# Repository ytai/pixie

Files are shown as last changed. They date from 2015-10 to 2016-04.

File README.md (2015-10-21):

# Pixie
Design files for the Pixie 3W RGB LED product.

The Pixie is a 3W RGB smart LED module, designed by Ytai Ben-Tsvi and sold by Adafruit:
https://www.adafruit.com/products/2741

Image of Pixie

This is the home of its hardware design files and the firmware code.
While most users never need to worry about it, the Pixie features a PIC12F MCU, which can be reprogrammed for changing its behavior.

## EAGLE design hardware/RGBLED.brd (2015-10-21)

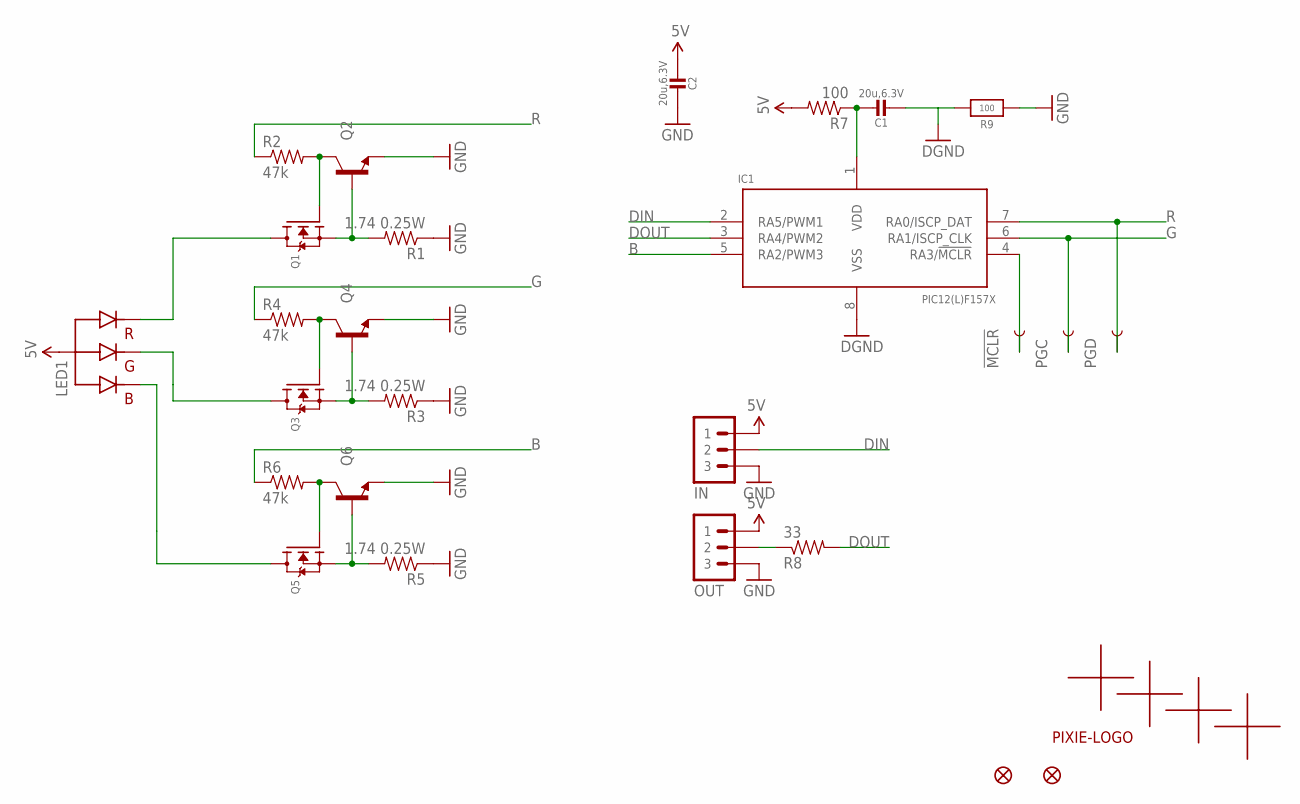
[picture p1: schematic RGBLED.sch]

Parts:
!MCLR: TEST-POINT3X4; PAD.03X.04
C1, C2: 20u,6.3V; _0805MP
IC1: PIC12(L)F157X; MSOP-8
IN: M030.1PWR+SIG; 1X03-0.1PWR+SIG
LED1: RGBLED_CA; RGBLED3W4PIN
OUT: M030.1PWR+SIG; 1X03-0.1PWR+SIG
PGC: TEST-POINT3X4; PAD.03X.04
PGD: TEST-POINT3X4; PAD.03X.04
Q1, Q3, Q5: IRLML2060TRPBF; SOT23-3
Q2, Q4, Q6: MMBT2222A; SOT23-3
R1, R3, R5: 1.74 0.25W; 1206
R2, R4, R6: 47k; 0603-RES
R7: 100; 0603-RES
R8: 33; 0603-RES
R9: 100; _0603MP
U$1, U$2, U$3, U$4: ALIGN_CROSS
U$5: PIXIE-LOGO
U$6, U$7: FIDUCIAL""; FIDUCIAL_1MM

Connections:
5V: C2.2, IN.P$1 (1), LED1.ANODE (VCC), OUT.P$1 (1), R7.2
B: IC1.5 (RA2/PWM3), R6.1
DGND: C1.2, IC1.8 (VSS), R9.2
DIN: IC1.2 (RA5/PWM1), IN.P$2 (2)
DOUT: IC1.3 (RA4/PWM2), R8.2
G: IC1.6 (RA1/ISCP_CLK), PGC.P$1, R4.1
GND: C2.1, IN.P$3 (3), OUT.P$3 (3), Q2.2 (E), Q4.2 (E), Q6.2 (E), R1.1, R3.1, R5.1, R9.1
unnamed: LED1.R (RED), Q1.3 (D)
unnamed: LED1.G (GREEN), Q3.3 (D)
unnamed: LED1.B (BLUE), Q5.3 (D)
unnamed: Q1.2 (S), Q2.1 (B), R1.2
unnamed: Q3.2 (S), Q4.1 (B), R3.2
unnamed: OUT.P$2 (2), R8.1
unnamed: !MCLR.P$1, IC1.4 (RA3/!MCLR)
unnamed: Q5.1 (G), Q6.3 (C), R6.2
unnamed: Q3.1 (G), Q4.3 (C), R4.2
unnamed: C1.1, IC1.1 (VDD), R7.1
unnamed: Q5.2 (S), Q6.1 (B), R5.2
unnamed: Q1.1 (G), Q2.3 (C), R2.2
R: IC1.7 (RA0/ISCP_DAT), PGD.P$1, R2.1

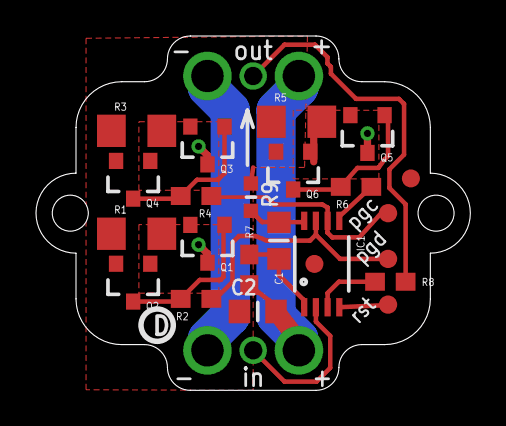
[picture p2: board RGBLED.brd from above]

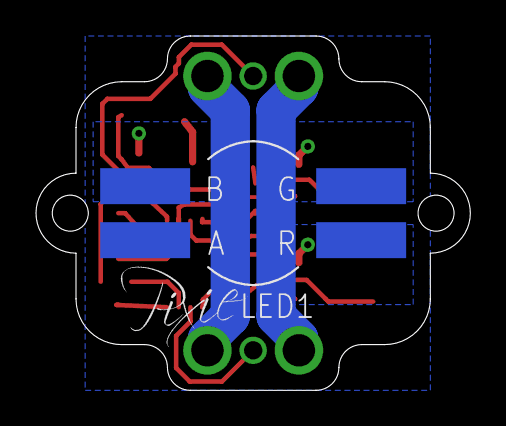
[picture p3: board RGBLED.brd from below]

Board: 2 copper layers, 24.1 x 19.7 mm, 32 parts (2 on the bottom side), 20 nets.

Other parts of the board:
U$8: PCBFEAT-REV-040

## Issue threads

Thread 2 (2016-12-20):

Low power mode?

jgilbert20, 2016-12-20:
Love the pixie but see that its drawing 3mA even when not lit. Would be great to have a low power mode that would support battery operation with long periods of inactivity.

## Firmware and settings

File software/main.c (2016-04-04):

#include <stdbool.h>
#include <stdint.h>

#include <xc.h>

#pragma config FOSC = INTOSC, WDTE = ON, CP = OFF, PLLEN = ON, BOREN = OFF, MCLRE = ON, CLKOUTEN = OFF, PWRTE = OFF, LPBOREN = ON,

#define DIN_PIN_MASK (1 << 5)
#define DOUT_PIN_MASK (1 << 4)
#define RED_PIN_MASK   (1 << 0)
#define GREEN_PIN_MASK (1 << 1)
#define BLUE_PIN_MASK  (1 << 2)
#define RGB_PIN_MASK (RED_PIN_MASK | GREEN_PIN_MASK | BLUE_PIN_MASK)

// How long of a silence on the line is considered a latch event.
// Units are 32[us] per count.
#define LATCH_TIME 30

// To convert this value to real temperature (in Celcius):
// T = K -temperature * 1.5151515, where K is some calibration constant,
// typically around 320.
static uint8_t temperature;
static uint8_t max_temp;

static uint8_t r, g, b;
uint8_t color_array[24];
volatile uint8_t bit_count;

static void InitializePwm() {
  // Fosc, no prescaler = 32MHz. Full cycle will be: 32MHz / 2^16 = 488Hz
  PWM1CLKCON = 0;
  PWM2CLKCON = 0;
  PWM3CLKCON = 0;

  // Set the period to 2^16
  PWM1PRH = PWM1PRL = 0xFF;
  PWM2PRH = PWM2PRL = 0xFF;
  PWM3PRH = PWM3PRL = 0xFF;

  // Set the phase to 0.
  PWM1PHH = PWM1PHL = 0;
  PWM2PHH = PWM2PHL = 0;
  PWM3PHH = PWM3PHL = 0;

  // Set the offset to 0.
  PWM1OFH = PWM1OFL = 0;
  PWM2OFH = PWM2OFL = 0;
  PWM3OFH = PWM3OFL = 0;

  // Set the duty cycle to 0.
  PWM1DC = 0;
  PWM2DC = 0;
  PWM3DC = 0;

  // Latch the values on next trigger.
  PWMLD = 0x07;

  // Enable the output pins.
  PWM1CON = 0x40;
  PWM2CON = 0x40;
  PWM3CON = 0x40;

  // Enable all PWM modules.
  PWMEN = 0x07;
}

static void InitializePins() {
  // Disable analog inputs.
  ANSELA = 0;
  // All outputs but Dout are low.
  LATA = DOUT_PIN_MASK;
  // Weak pull-up on Din.
  WPUA = DIN_PIN_MASK;
  // Schmidt-trigger input on Din.
  INLVLA = DIN_PIN_MASK;
  // Set the output pins as output.
  TRISA = ~(RGB_PIN_MASK | DOUT_PIN_MASK);
}

static void InitializeTimers() {
  // Timer 0 : Instruction clock / 256 = 31.25kHz (32us).
  OPTION_REG = 0x07;

  // Timer 1: Instruction clock / 8 = 1MHz (1us).
  T1CON = 0x31;

  // Timer 2: Instruction clock / 16 = 500kHz (2us).
  T2CON = 0x06;
}

static void InitializeTemperature() {
  // Enable temperature indicator at high range and FVR.
  FVRCON = 0xB0;

  // Configure ADC.
  ADCON2 = 0x00;
  // Left-aligned, Tad = 1us.
  ADCON1 = 0x20;

  // Wait for FVR to settle.
  while (!FVRRDY);
}

static inline void Timer1Delay(uint16_t count) {
  TMR1 = 0;
  while (TMR1 < count);
}

static inline uint16_t AcquireTemperature() {
  // Configure the ADC to acquire the temperature indicator.
  ADCON0 = 0x75;

  // Wait for acquisition (200us).
  Timer1Delay(200);

  // Sample.
  GO = 1;       // Start.
  while (GO);   // Wait completion.

  return ADRES;
}

static inline uint16_t AcquireVref() {
    // Enable the FVR amplifier (2x)
  FVRCON = 0xB2;

  // Configure the ADC to acquire the FVR.
  ADCON0 = 0x7D;

  // Wait for acquisition (50us).
  Timer1Delay(50);

  // Sample.
  GO = 1;       // Start.
  while (GO);   // Wait completion.

  // Disable the FVR amplifier.
  FVRCON = 0xB0;

  return ADRES;
}

static void ReadTemperature() {
  uint16_t v1 = AcquireVref();
  uint16_t t = AcquireTemperature();
  uint16_t v2 = AcquireVref();

  // Turn ADC off.
  ADCON0 = 0;

  uint8_t vavg = ((v1 >> 1) + (v2 >> 1) + 128) >> 8;
  temperature = (0xFFC0 - t) / vavg - 200;
}

static void ConvertColor() {
  r = g = b = 0;

  // Note the the temperature units used are reversed: bigger number == lower
  // temperature. So the condition below actually means temp <= max_temp.
  if (temperature >= max_temp && bit_count == 1) {
    uint8_t i;
    uint8_t const * p = color_array;

    // Read Red bits.
    for (i = 0; i < 8; ++i) {
      r |= ((*p++ >> 5) & 1) << i;
    }

    // Read Green bits.
    for (i = 0; i < 8; ++i) {
      g |= ((*p++ >> 5) & 1) << i;
    }

    // Read Blue bits.
    for (i = 0; i < 8; ++i) {
      b |= ((*p++ >> 5) & 1) << i;
    }
  }
}

static void LatchColor() {
  // Prepare the new values in the PWM periods.
  PWM1DC = (uint16_t) g * g;
  PWM2DC = (uint16_t) r * r;
  PWM3DC = (uint16_t) b * b;

  // Latch all at once.
  PWMLD = 0x07;
}

static inline void SerialSend(uint8_t b) {
  // Start bit.
  LATA &= ~DOUT_PIN_MASK;
  Timer1Delay(99);
  for (unsigned i = 0; i < 8; ++i) {
    if (b & 1) {
      LATA |= DOUT_PIN_MASK;
    } else {
      LATA &= ~DOUT_PIN_MASK;
    }
    b >>= 1;
    Timer1Delay(99);
  }
  // Stop bit.
  LATA |= DOUT_PIN_MASK;
  Timer1Delay(99);
}

static uint8_t ReadMaxTemperature() {
  PMADR = 0x8000;
  CFGS = 1;
  RD = 1;
  asm("nop\nnop\n");
  return PMDATL;
}

void main() {
  // High speed.
  OSCCONbits.IRCF = 0xe;

  InitializePwm();
  InitializePins();
  InitializeTimers();
  InitializeTemperature();

  max_temp = ReadMaxTemperature();
  if (max_temp == 0xFF) {
    for (;;) {
      ReadTemperature();
      SerialSend(temperature);

      CLRWDT();
      Timer1Delay(1000);
    }
  }

  // Enable interrupts on any edge of DIN.
  IOCAP5 = 1;
  IOCAN5 = 1;
  IOCIE = 1;

  // Wait for silence. Do not take interrupts and do not set the output.
  TMR0 = 0;
  while (TMR0 < LATCH_TIME) {
    if (IOCAF5) {
      TMR0 = 0;
      IOCAF5 = 0;
    }
  }

  // Main loop.
  while (true) {
    // FSR0 needs to point to the beginning of the color array.
    FSR0 = (uint16_t) color_array;

    // And we have 24 bits left to read (+1, as 1 means done).
    bit_count = 25;

    // Ready to handle interrupts. Clear first.
    IOCAF5 = 0;
    GIE = 1;

    // Wait for read to start. The interrupt handler will decrement bit_count.
    while (bit_count == 25);

    // Then, wait for silence of LATCH_TIME. The interrupt handler will clear
    // timer 0 on every edge, so we'll get out of this loop only after
    // LATCH_TIME with no edges.
    TMR0 = 0;
    while (TMR0 < LATCH_TIME);

    // Disable interrupts while processing.
    GIE = 0;

    // Read the temperature. This should take ~400us.
    ReadTemperature();
  
    // Convert the color read by the interrupt handler.
    ConvertColor();

    // The color array not contains the 24 bits we've read. Latch.
    LatchColor();

    // Clear the watchdog.
    CLRWDT();
  }
}

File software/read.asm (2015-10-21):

#include <xc.inc>

GLOBAL _bit_count

wait MACRO cy3
    movlw cy3
    decfsz WREG
    bra $-1
ENDM

sample_bit_and_wait MACRO
    movf PORTA, w         ; Sample PORTA. Bit 5 is the input.
    movwi FSR0++          ; Save the bit into the color array.
    wait 22
    nop
ENDM

PSECT intentry,class=CODE,reloc=2,delta=2
    BANKSEL PORTA
    decfsz _bit_count, f  ; Decrement bit count. If zero, we're in echo mode.
    bra read_mode

    ; echo mode handling.
    lsrf PORTA, f         ; Shift the input bit to the output position.
                          ; We're setting all PORTA bits, but bit 4 is the only output.

  cleanup:
    clrf TMR0             ; Clear the idle time counter.
    movlw 1               ; Increment bit count.
    addwf _bit_count
    BANKSEL IOCAF         ; Clear the interrupt.
    clrf BANKMASK(IOCAF)
    retfie

    ; read mode handling.
  read_mode:
    ; Was this a falling edge (start bit)? Otherwise, ignore it.
    btfsc PORTA, 5
    bra cleanup

    ; At this point, 6 cycles have elapsed since the beginning of the ISR
    ; + between 3-4 cycles since the edge. Total: 9-10 cycles. Our first sample
    ; takes place 1.5 serial bits from the edge, or 13[us] or 104 cycles.
    ; Let's then idle for 94 cycles (=93+1).
    wait 31
    nop

    ; Repeat 8 times: sample, then wait until a period of 1 serial bit time or
    ; about 69 cycles has elapsed.
    sample_bit_and_wait
    sample_bit_and_wait
    sample_bit_and_wait
    sample_bit_and_wait
    sample_bit_and_wait
    sample_bit_and_wait
    sample_bit_and_wait
    sample_bit_and_wait
    ; We should be on the stop bit now.

    ; Decrement 8 from bit_count.
    movlw 8
    subwf _bit_count, f

    ; Save FSR0 to the shadow register.
    movf FSR0L, w
    BANKSEL FSR0L_SHAD
    movwf BANKMASK(FSR0L_SHAD)

    bra cleanup

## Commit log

2015-10-21 Improved temperature calculation
2015-10-21 Free up timer 2
    Use timer 1 instead. Timer 2 supports interrupt on match.
2015-10-21 Upon long silence, move on even if we didn't get 24 bits.
    This is important for resync.
    [main.c]
2015-10-21 Clear lingering interrupts before enabling
2015-10-21 Support UART mode
2015-10-21 Fix error in temperature constants
    [main.c]
2015-10-21 Temperature calibration mode
    Max temperature is stored as a user ID value and read in runtime.
    Initially, if it is unset (0xFF), we go into a mode where we spit out
    temperature readings as a 9600 8N1 serial stream over the DOUT pin.
2015-10-21 Initial commit of hardware design files
    [RGBLED.brd, RGBLED.sch]
2016-04-04 Increase reference voltage conversion time
    Experiments show that the reading does not stabilize within 20us.
    50us looks a lot better.
    [main.c]
2016-04-04 Avoid watchdog reset during temperature emission
    [main.c]

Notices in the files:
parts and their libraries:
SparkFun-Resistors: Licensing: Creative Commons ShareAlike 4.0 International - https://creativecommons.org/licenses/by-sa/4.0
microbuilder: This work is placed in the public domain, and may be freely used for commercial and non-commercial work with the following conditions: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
